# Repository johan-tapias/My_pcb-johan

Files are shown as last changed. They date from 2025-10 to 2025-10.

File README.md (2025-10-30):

# Johan Tapias

## pathfinder session 1 - [I dedicated 4 hours to the project]
what I did: 
I imported the controller symbol and the LED symbol and made the circuit diagram

Screenshot of progress:  



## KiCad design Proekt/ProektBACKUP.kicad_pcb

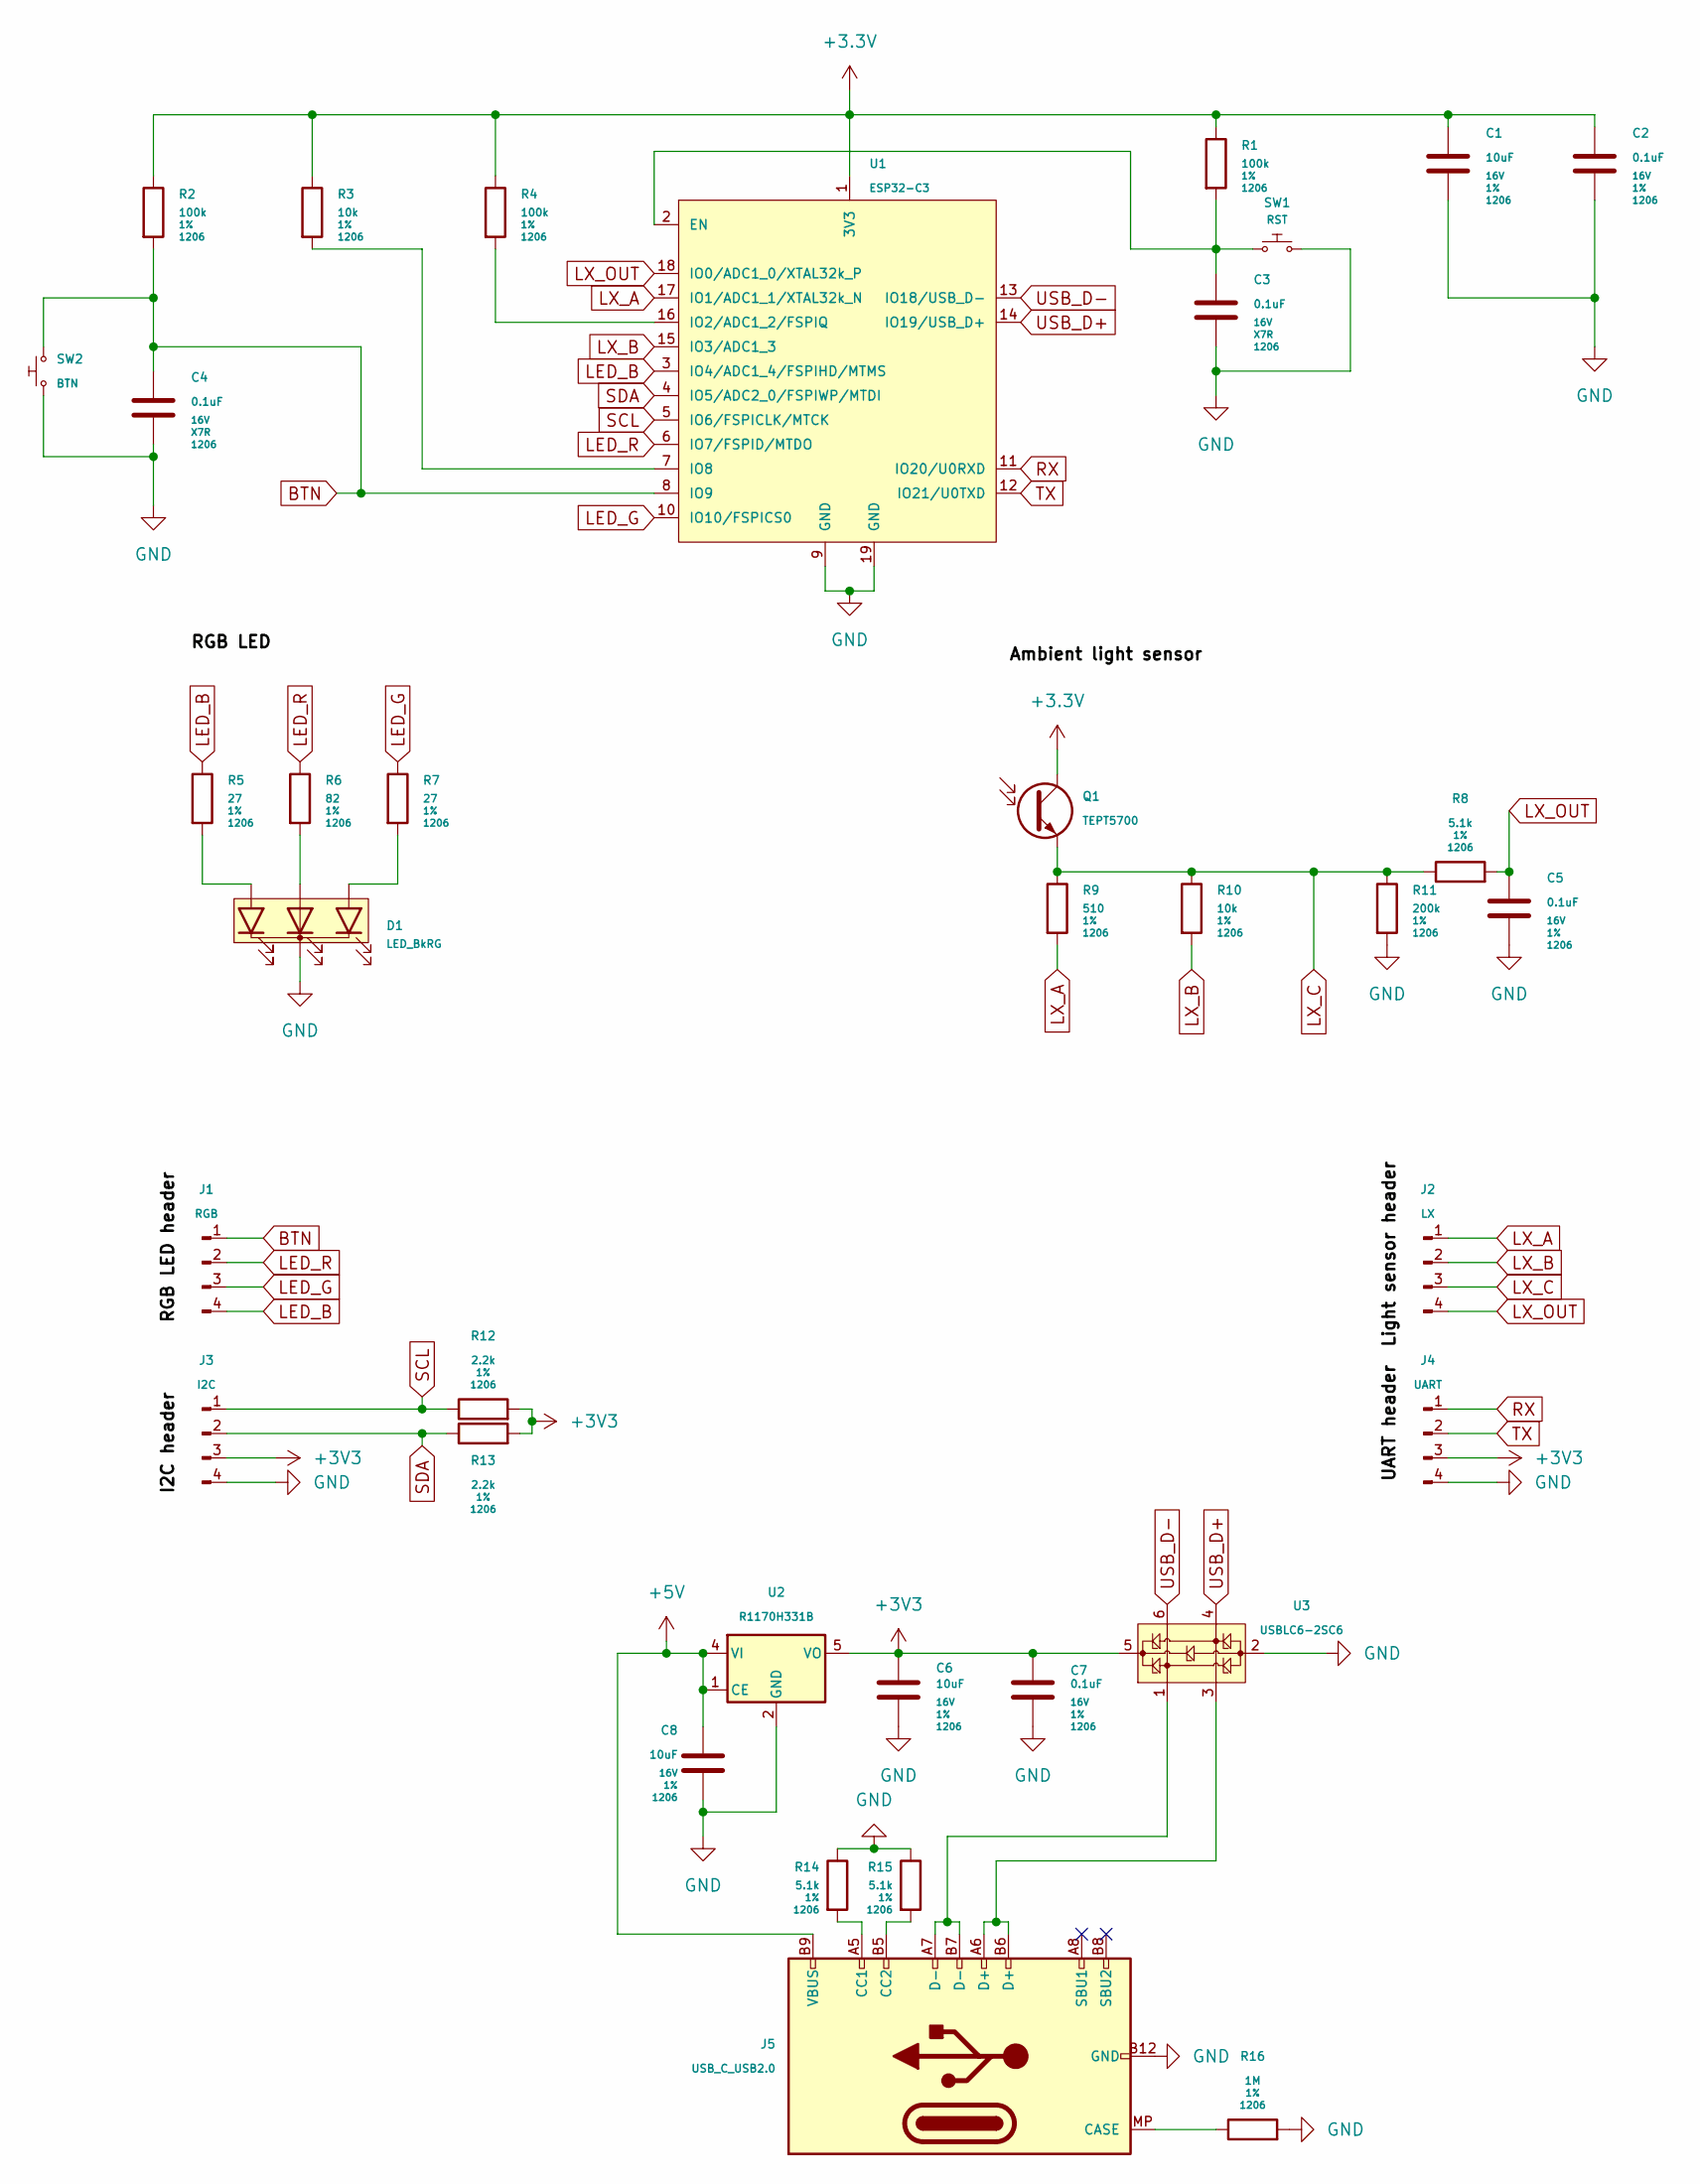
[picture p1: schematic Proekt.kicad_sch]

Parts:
C1, C6, C8: 10uF; C_1206_(3216); Voltage 16V; Tolerance 1%
C2, C5, C7: 0.1uF; C_1206_(3216); Voltage 16V; Tolerance 1%
C3, C4: 0.1uF; C_1206_(3216); Voltage 16V; Tolerance X7R
D1: LED_BkRG; LED_D5.0mm-4_RGB
J1: RGB; PinHeader_1x04_P2.54mm_Vertical
J2: LX; PinHeader_1x04_P2.54mm_Vertical
J3: I2C; PinHeader_1x04_P2.54mm_Vertical
J4: UART; PinHeader_1x04_P2.54mm_Vertical
J5: USB_C_USB2.0; USB-C_MOLEX-216990-0001
Q1: TEPT5700; PT_D5.0mm
R1, R2, R4: 100k; R_1206_(3216); Tolerance 1%
R3, R10: 10k; R_1206_(3216); Tolerance 1%
R5, R7: 27; R_1206_(3216); Tolerance 1%
R6: 82; R_1206_(3216); Tolerance 1%
R8, R14, R15: 5.1k; R_1206_(3216); Tolerance 1%
R9: 510; R_1206_(3216); Tolerance 1%
R11: 200k; R_1206_(3216); Tolerance 1%
R12, R13: 2.2k; R_1206_(3216); Tolerance 1%
R16: 1M; R_1206_(3216); Tolerance 1%
SW1: RST; SW_PUSH_6mm_SMD
SW2: BTN; SW_PUSH_6mm_SMD
U1: ESP32-C3; ESP32-C3-WROOM-02
U2: R1170H331B; SOT-89-5
U3: USBLC6-2SC6; SOT-23-6

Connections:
+5V: C8.1, J5.A4 (VBUS), J5.A9 (VBUS), J5.B4 (VBUS), J5.B9 (VBUS), U2.1 (CE), U2.4 (VI)
BTN: C4.1, J1.1, R2.2, SW2.COM, U1.8 (IO9)
GND: C1.2, C2.2, C3.1, C4.2, C5.2, C6.2, C7.2, C8.2, D1.K, J3.4, J4.4, J5.A1 (GND), J5.A12 (GND), J5.B1 (GND), J5.B12 (GND), R11.2, R14.1, R15.1, R16.2, SW1.COM, SW2.NO, U1.9 (GND), U1.19 (GND), U2.2 (GND), U3.2 (GND)
LED_B: J1.4, R5.1, U1.3 (IO4/ADC1_4/FSPIHD/MTMS)
LED_G: J1.3, R7.1, U1.10 (IO10/FSPICS0)
LED_R: J1.2, R6.1, U1.6 (IO7/FSPID/MTDO)
LX_A: J2.1, R9.2, U1.17 (IO1/ADC1_1/XTAL32k_N)
LX_B: J2.2, R10.2, U1.15 (IO3/ADC1_3)
LX_C: J2.3, Q1.E, R8.1, R9.1, R10.1, R11.1
LX_OUT: C5.1, J2.4, R8.2, U1.18 (IO0/ADC1_0/XTAL32k_P)
unnamed: D1.Ab (Ablue), R5.2
unnamed: D1.Ag (Agreen), R7.2
unnamed: D1.Ar (Ared), R6.2
unnamed: J5.MP (CASE), R16.1
unnamed: J5.A5 (CC1), R14.2
unnamed: J5.B5 (CC2), R15.2
unnamed: J5.A6 (D+), J5.B6 (D+), U3.3 (I/O2)
unnamed: J5.A7 (D-), J5.B7 (D-), U3.1 (I/O1)
unnamed: C3.2, R1.2, SW1.NO, U1.2 (EN)
unnamed: R4.2, U1.16 (IO2/ADC1_2/FSPIQ)
unnamed: R3.2, U1.7 (IO8)
RX: J4.1, U1.11 (IO20/U0RXD)
SCL: J3.1, R12.1, U1.5 (IO6/FSPICLK/MTCK)
SDA: J3.2, R13.1, U1.4 (IO5/ADC2_0/FSPIWP/MTDI)
TX: J4.2, U1.12 (IO21/U0TXD)
USB_D+: U1.14 (IO19/USB_D+), U3.4 (I/O2)
USB_D-: U1.13 (IO18/USB_D-), U3.6 (I/O1)

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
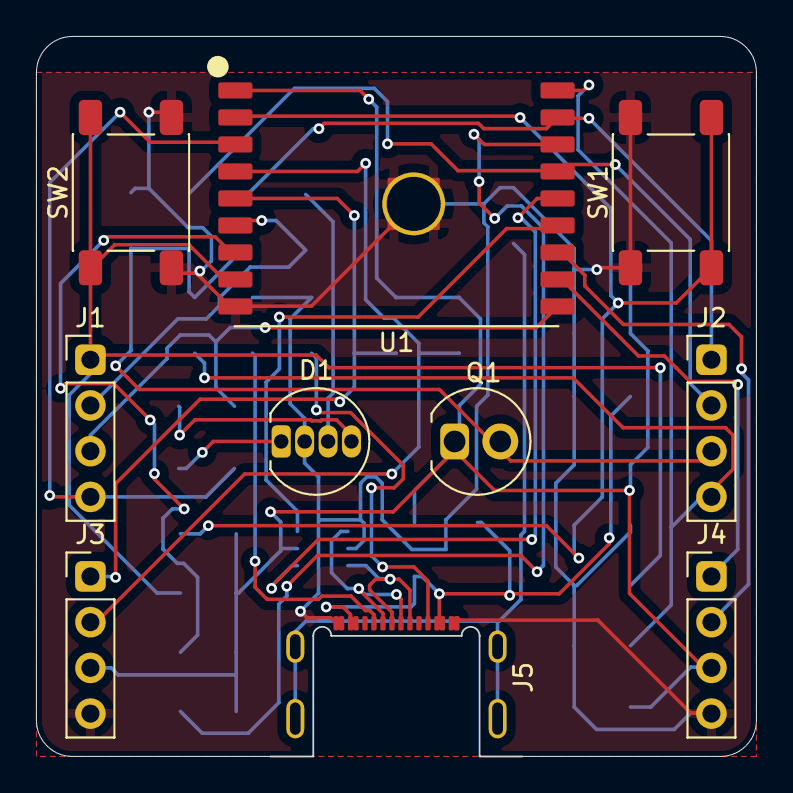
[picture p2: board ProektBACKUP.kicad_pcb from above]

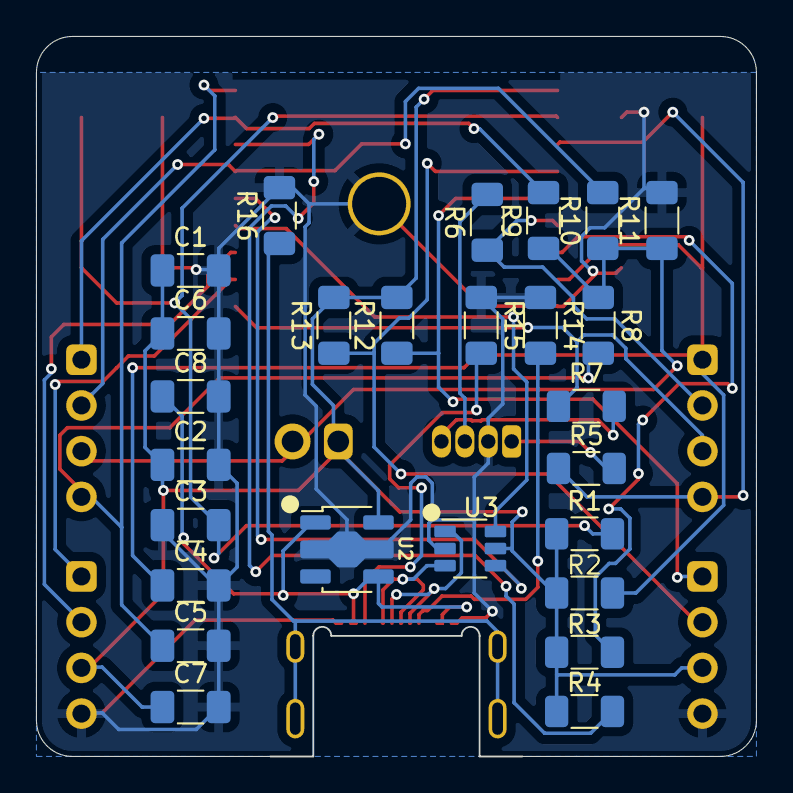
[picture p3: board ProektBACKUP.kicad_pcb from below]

Board: 2 copper layers, 40.0 x 40.0 mm, 36 parts (26 on the bottom side), 28 nets.
